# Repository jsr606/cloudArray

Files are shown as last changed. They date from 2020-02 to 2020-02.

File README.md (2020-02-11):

# cloud array
github repository for the tech side of the permanent installation "cloud array".

this installation lives permanently at [søndervangskolen](https://soendervangskolen.aarhus.dk/) in viby, århus, denmark. you can see the installation from the inside as well as the outside 24 hours a day, all year.

for more information visit this website www.jacobremin.com/cloudArray

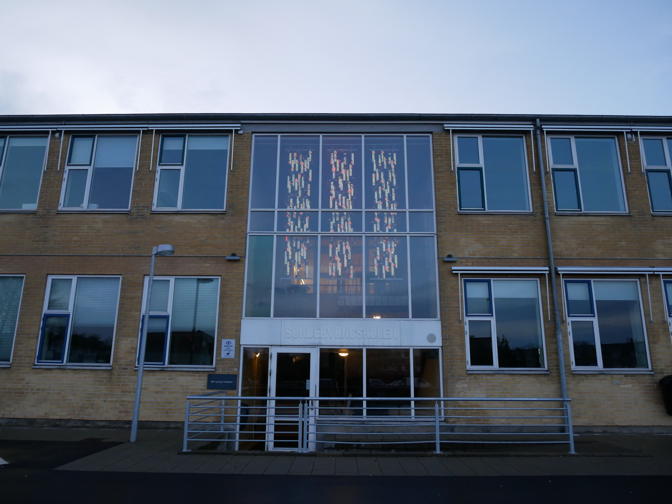
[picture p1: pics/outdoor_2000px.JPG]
installation view, photo by jacob remin

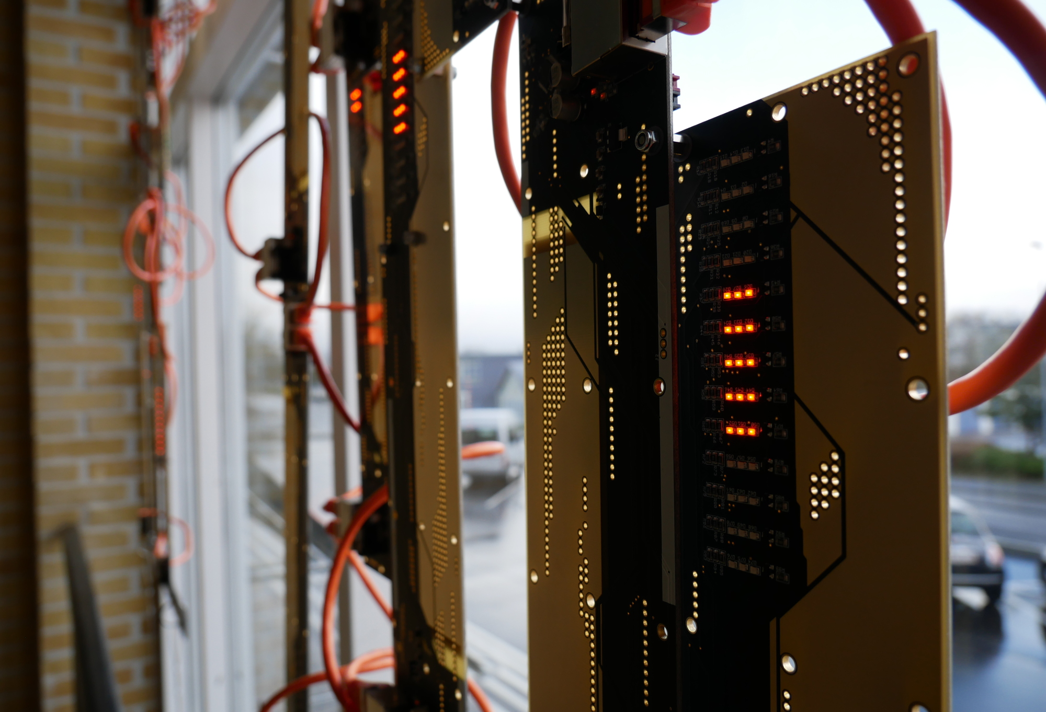
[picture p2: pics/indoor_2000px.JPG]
installation detail, photo by jacob remin


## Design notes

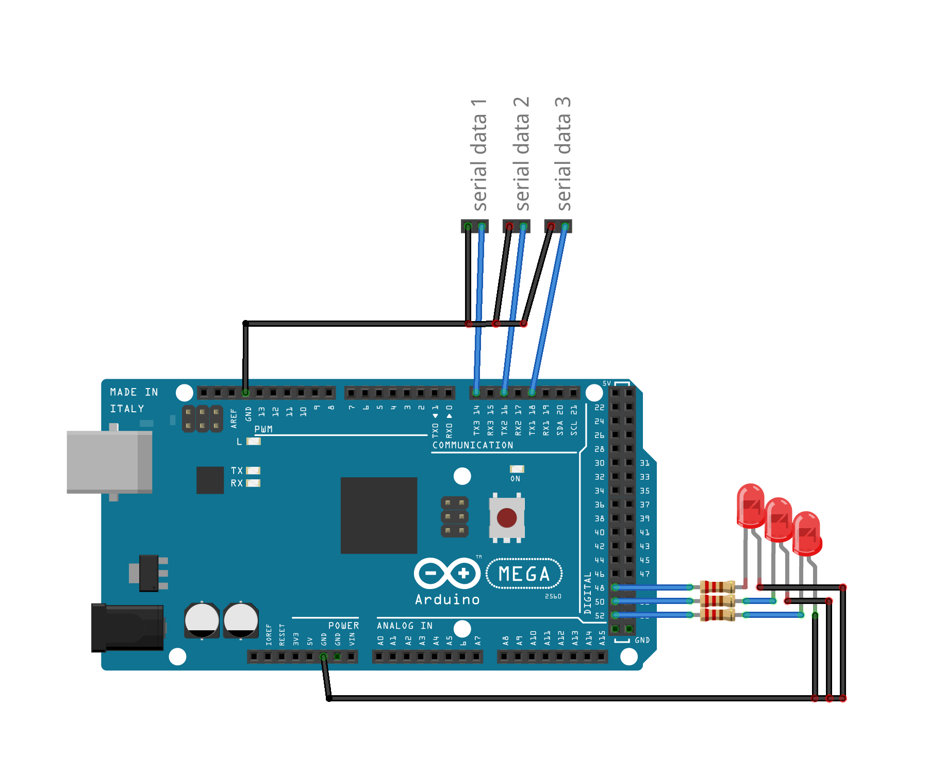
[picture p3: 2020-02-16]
hardware and documentation/mega conductor.png

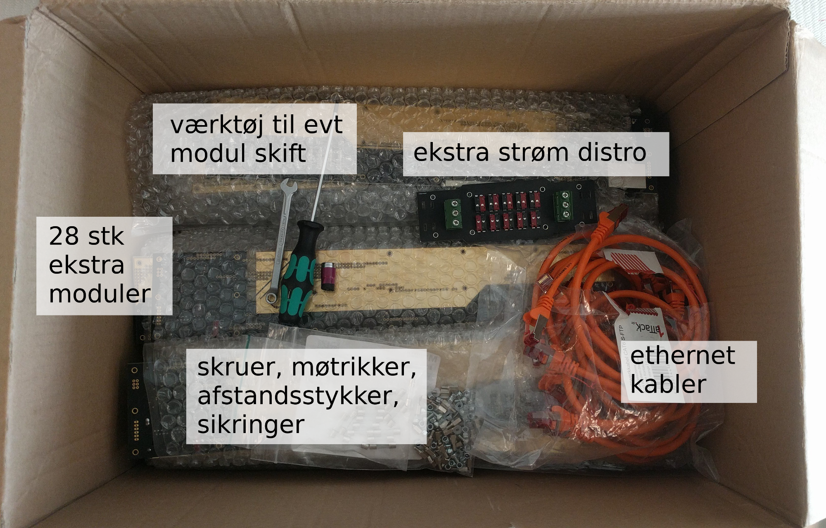
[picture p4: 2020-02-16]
hardware and documentation/extra things for søndervangskolen.png

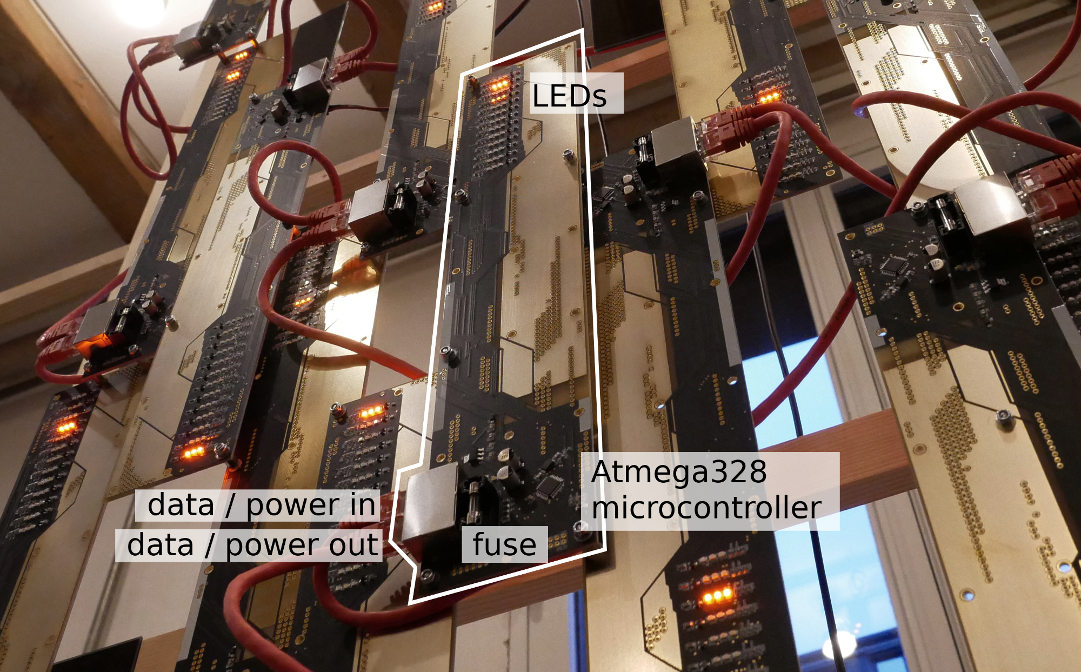
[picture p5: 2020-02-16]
hardware and documentation/annotated module.png

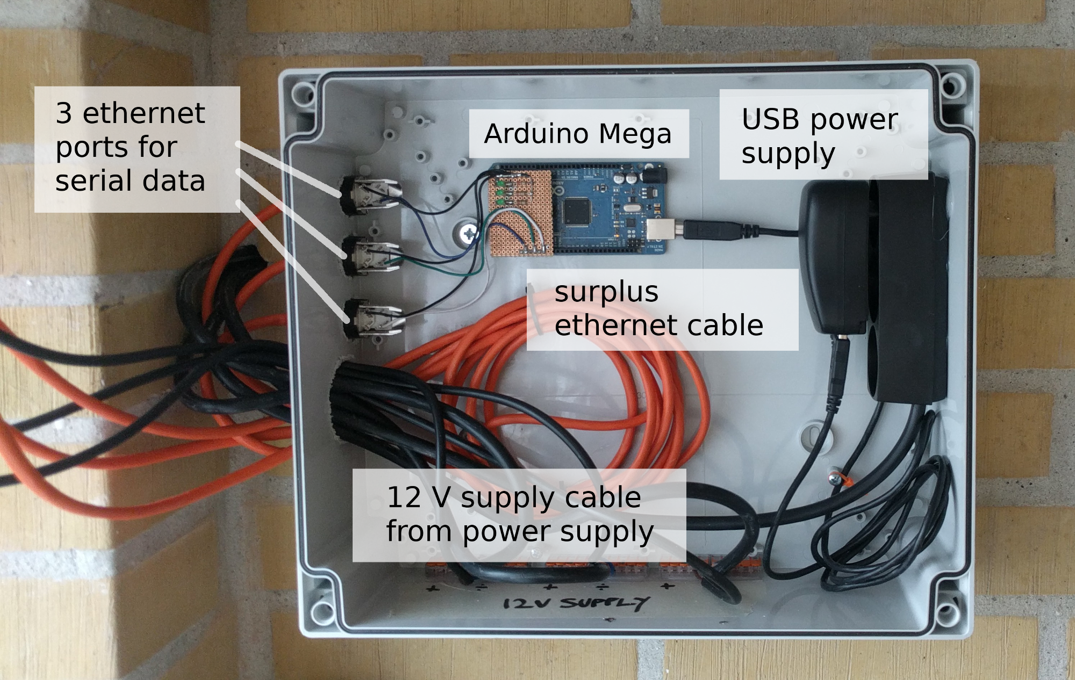
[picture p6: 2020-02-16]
hardware and documentation/annotated control box.png

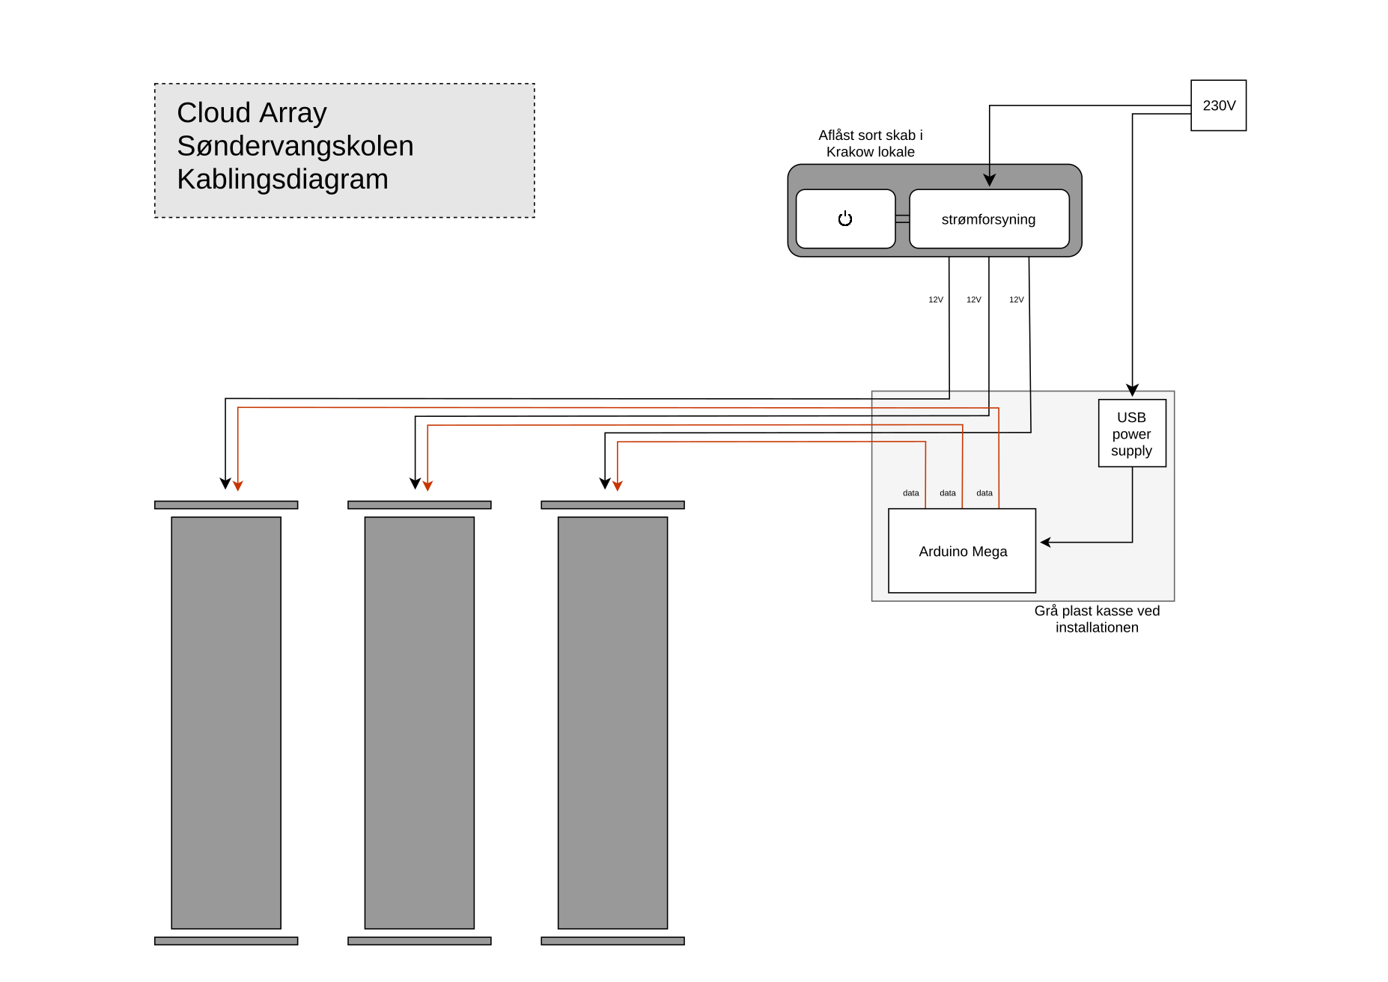
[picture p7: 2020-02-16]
hardware and documentation/cloud array kablingsdiagram.pdf.png

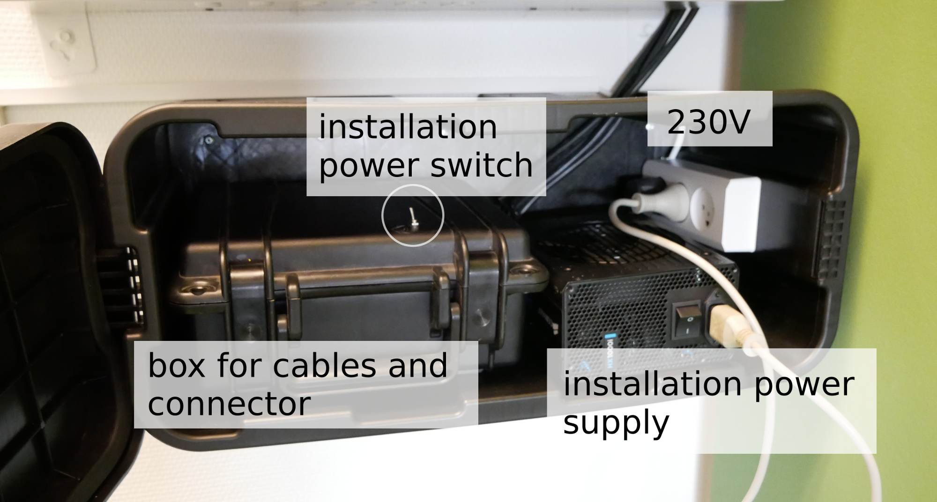
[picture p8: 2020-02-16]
hardware and documentation/annotated power cabinet.png

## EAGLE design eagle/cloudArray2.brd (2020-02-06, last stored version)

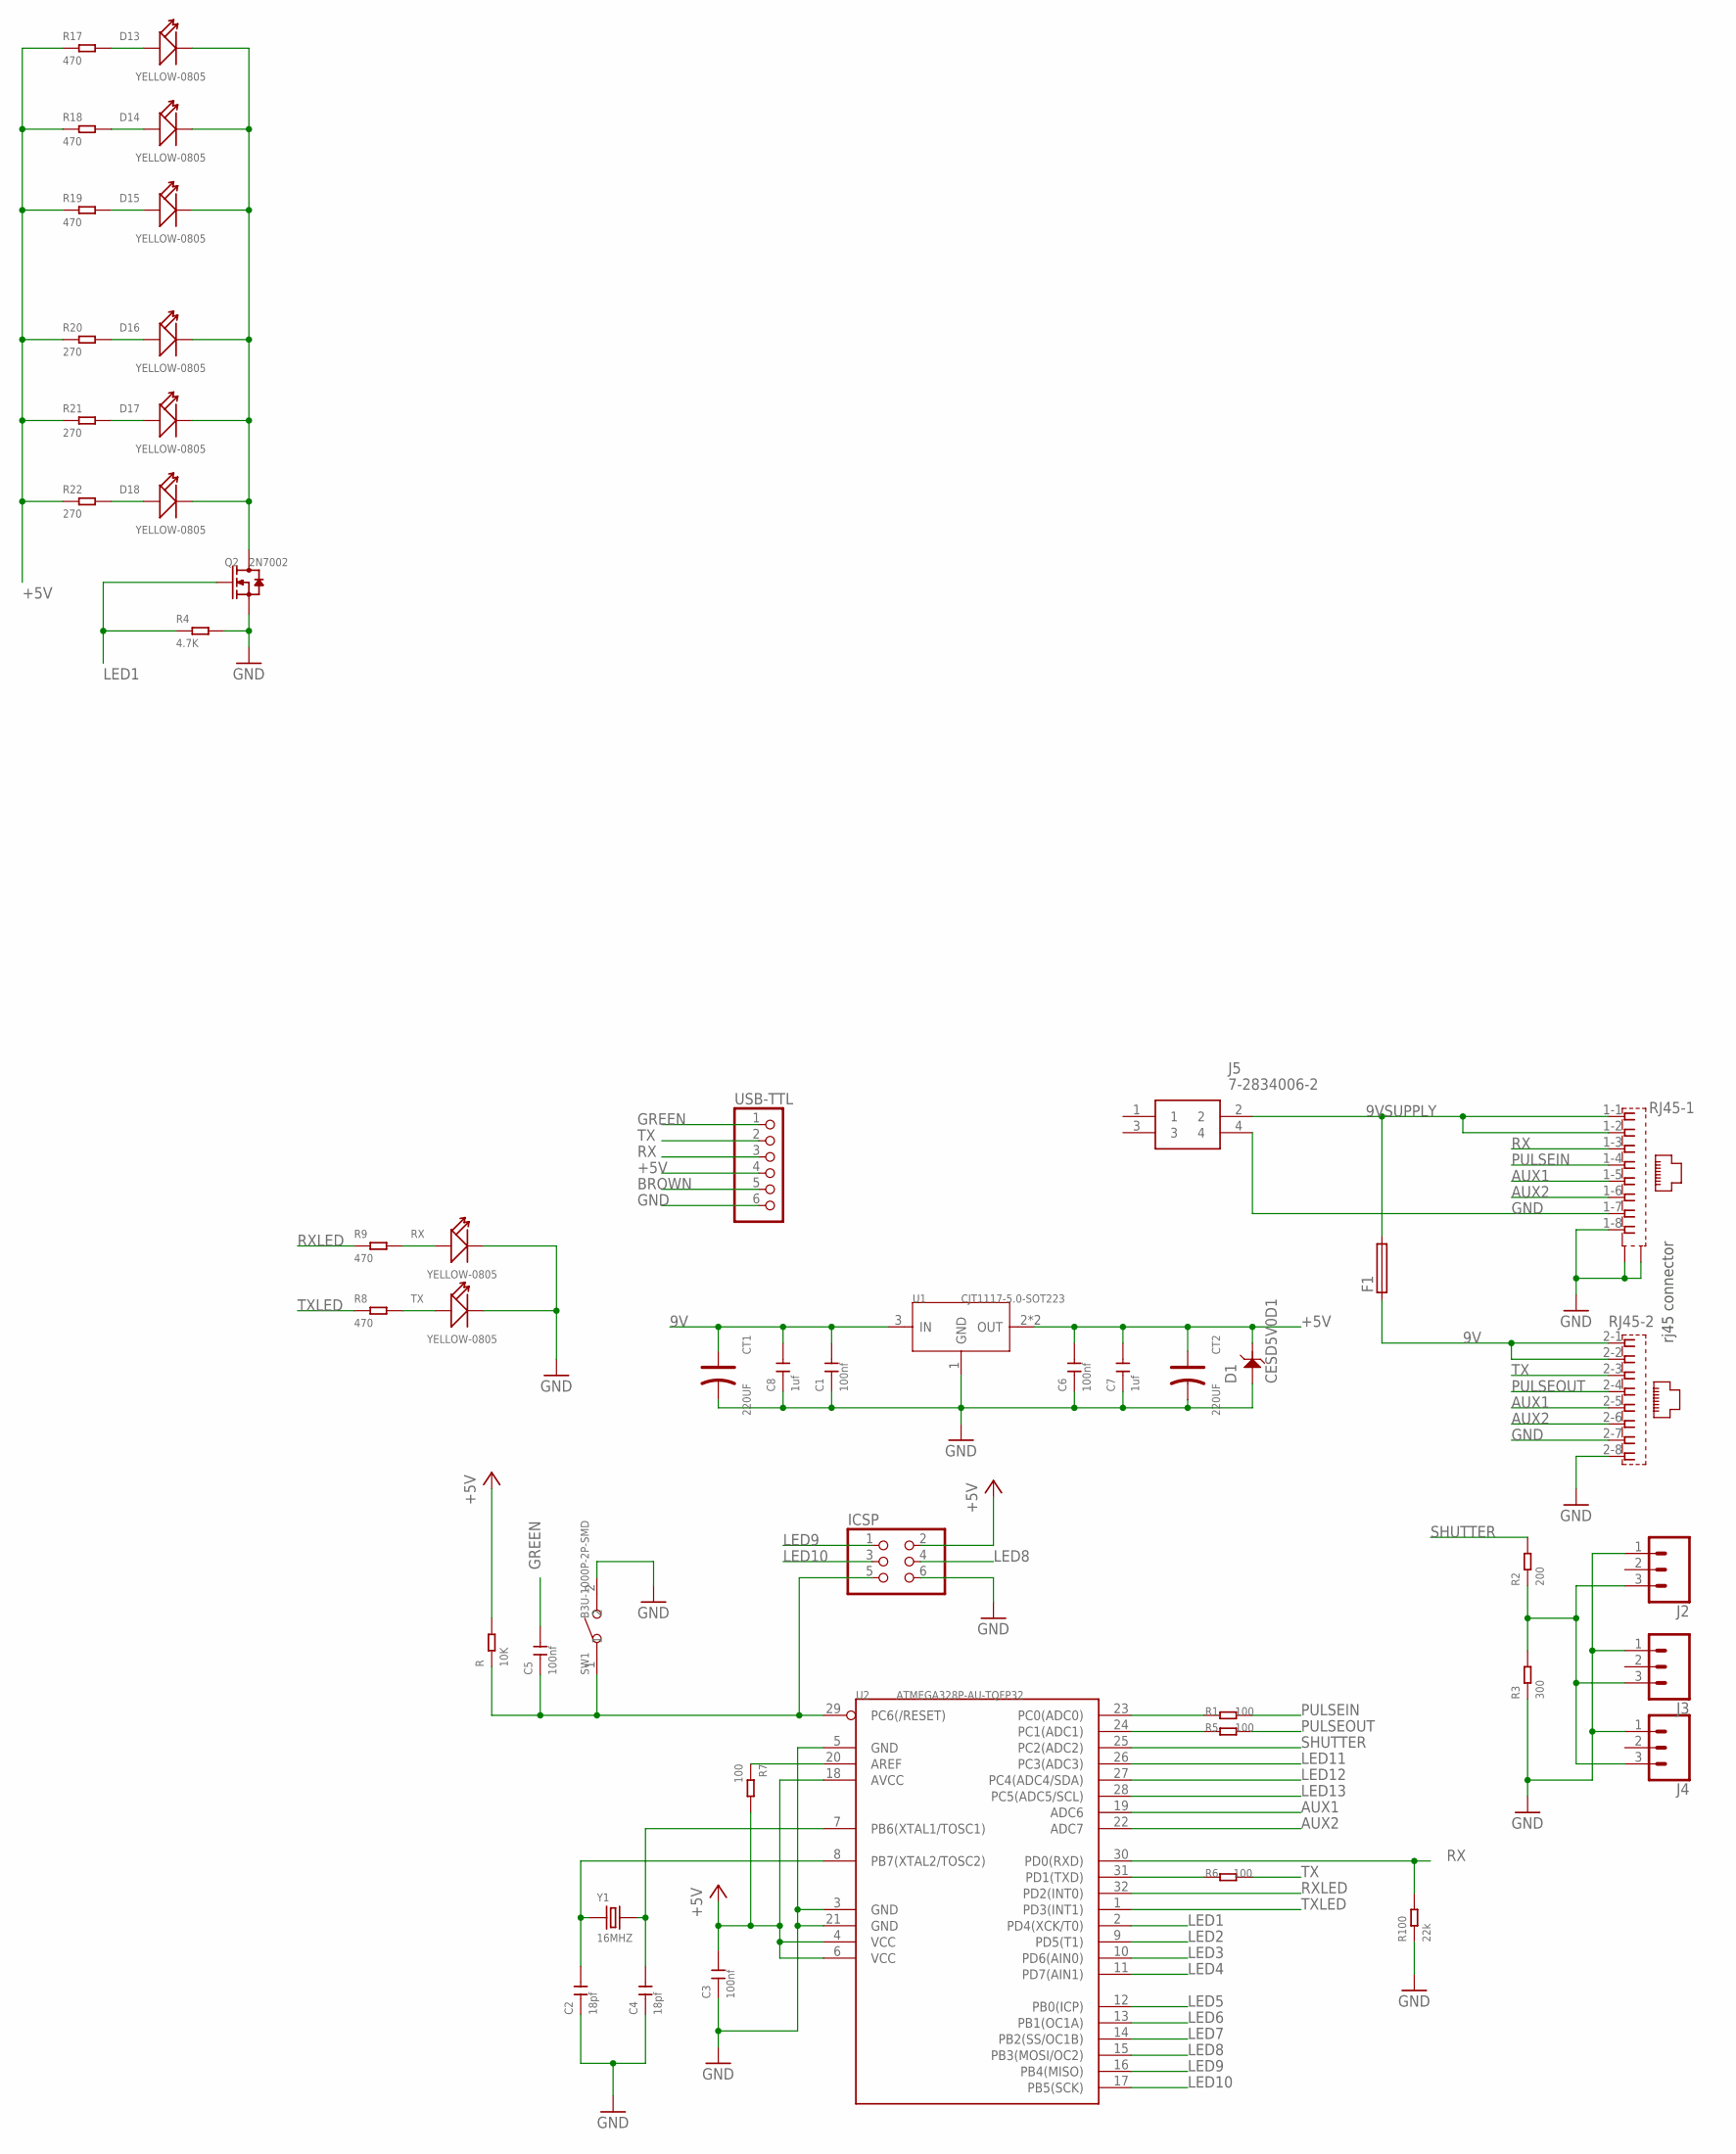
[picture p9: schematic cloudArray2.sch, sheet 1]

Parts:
C1, C3, C5, C6: 100nf; C0805
C2, C4: 18pf; C0805
C7, C8: 1uf; C0805
CT1, CT2: 220UF; ELECTRO-SMD-C-6MM
D1: CESD5V0D1; SOD-123
D13, D14, D15, D16, D17, D18: YELLOW-0805; LED-0805
F1: SH22,5A
ICSP: PINHD-2X3; 2X03
J2, J3, J4: 455-1750-1-ND; 1X03
J5: 7-2834006-2; 728340062
Q2: 2N7002; SOT-23
R: 10K; R0805
R1, R5, R6, R7: 100; R0805
R2: 200; R0805
R3: 300; R0805
R4: 4.7K; R0805
R8, R9, R17, R18, R19: 470; R0805
R20, R21, R22: 270; R0805
R100: 22k; R0805
RJ45: 557570-1
RX: YELLOW-0805; LED-0805
SW1: B3U-1000P-2P-SMD; SW2-2.6-3.0X2.5X1.2+0.4MM
TX: YELLOW-0805; LED-0805
U1: CJT1117-5.0-SOT223; SOT-223
U2: ATMEGA328P-AU-TQFP32; TQFP32-0.8-7X7MM
USB-TTL: PINHD-1X6; 1X06
Y1: 16MHZ; X2-SMD-5.0X3.2X1.3MM

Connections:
9V: C1.2, C8.2, CT1.+, F1.1, RJ45.2-1 (1), RJ45.2-2 (2), U1.3 (IN)
9VSUPPLY: F1.2, J5.2, RJ45.1-1 (1), RJ45.1-2 (2)
+5V: C3.2, C6.2, C7.2, CT2.+, D1.- (2), ICSP.2, R.2, R7.2, R17.1, R18.1, R19.1, R20.1, R21.1, R22.1, U1.2 (OUT), U1.TER (OUT), U2.4 (VCC), U2.6 (VCC), U2.18 (AVCC), USB-TTL.4; also elsewhere on the board
A0: R1.2, U2.23 (PC0(ADC0))
A1: R5.2, U2.24 (PC1(ADC1))
AREF: R7.1, U2.20 (AREF)
AUX1: RJ45.1-5 (5), RJ45.2-5 (5), U2.19 (ADC6)
AUX2: RJ45.1-6 (6), RJ45.2-6 (6), U2.22 (ADC7)
BROWN: USB-TTL.5
GND: C1.1, C2.1, C3.1, C4.1, C6.1, C7.1, C8.1, CT1.-, CT2.-, D1.+ (1), ICSP.6, J2.1, J3.1, J4.1, J5.4, Q2.2 (S), R3.1, R4.2, R100.1, RJ45.1-7 (7), RJ45.1-8 (8), RJ45.2-7 (7), RJ45.2-8 (8), RJ45.G1 (S2), RJ45.G3 (S1), RX.-, SW1.2, TX.-, U1.1 (GND), U2.3 (GND), U2.5 (GND), U2.21 (GND), USB-TTL.6; also elsewhere on the board
GREEN: C5.2, USB-TTL.1
LED1: Q2.1 (G), R4.1, U2.2 (PD4(XCK/T0))
LED2: U2.9 (PD5(T1)); also elsewhere on the board
LED3: U2.10 (PD6(AIN0)); also elsewhere on the board
LED4: U2.11 (PD7(AIN1)); also elsewhere on the board
LED5: U2.12 (PB0(ICP)); also elsewhere on the board
LED6: U2.13 (PB1(OC1A)); also elsewhere on the board
LED7: U2.14 (PB2(SS/OC1B)); also elsewhere on the board
LED8: ICSP.4, U2.15 (PB3(MOSI/OC2)); also elsewhere on the board
LED9: ICSP.1, U2.16 (PB4(MISO)); also elsewhere on the board
LED10: ICSP.3, U2.17 (PB5(SCK)); also elsewhere on the board
LED11: U2.26 (PC3(ADC3)); also elsewhere on the board
LED12: U2.27 (PC4(ADC4/SDA)); also elsewhere on the board
LED13: U2.28 (PC5(ADC5/SCL)); also elsewhere on the board
unnamed: D13.-, D14.-, D15.-, D16.-, D17.-, D18.-, Q2.3 (D)
unnamed: C2.2, U2.8 (PB7(XTAL2/TOSC2)), Y1.1
unnamed: C4.2, U2.7 (PB6(XTAL1/TOSC1)), Y1.2
unnamed: R6.2, U2.31 (PD1(TXD))
unnamed: R8.2, TX.+
unnamed: J2.3, J3.3, J4.3, R2.1, R3.2
unnamed: R9.2, RX.+
unnamed: D13.+, R17.2
unnamed: D14.+, R18.2
unnamed: D15.+, R19.2
unnamed: D16.+, R20.2
unnamed: D17.+, R21.2
unnamed: D18.+, R22.2
PULSEIN: R1.1, RJ45.1-4 (4)
PULSEOUT: R5.1, RJ45.2-4 (4)
RESET: C5.1, ICSP.5, R.1, SW1.1, U2.29 (PC6(/RESET))
RX: R100.2, RJ45.1-3 (3), U2.30 (PD0(RXD)), USB-TTL.3
RXLED: R9.1, U2.32 (PD2(INT0))
SHUTTER: R2.2, U2.25 (PC2(ADC2))
TX: R6.1, RJ45.2-3 (3), USB-TTL.2
TXLED: R8.1, U2.1 (PD3(INT1))

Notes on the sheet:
rj45 connector

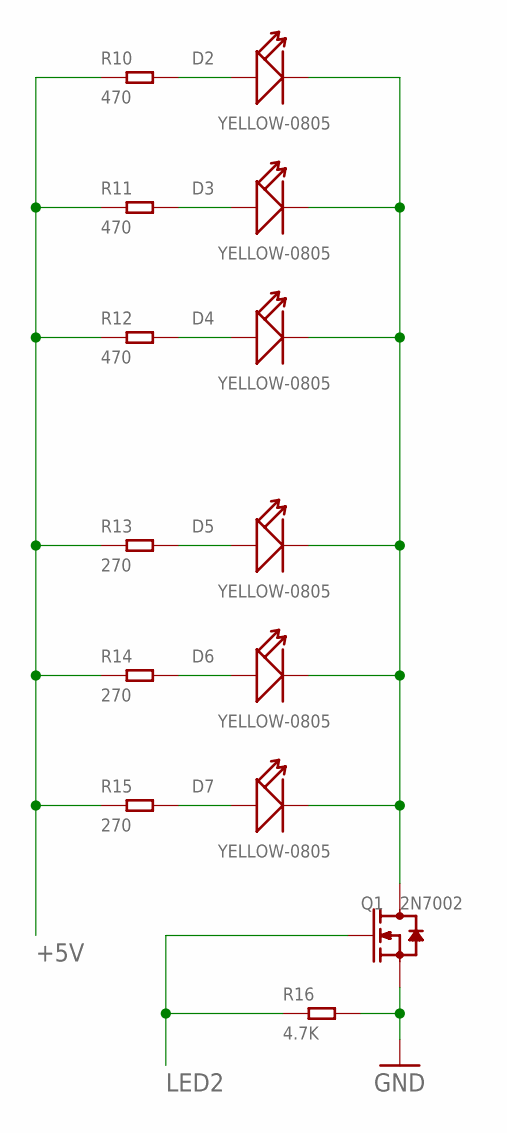
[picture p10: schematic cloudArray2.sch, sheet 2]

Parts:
D2, D3, D4, D5, D6, D7: YELLOW-0805; LED-0805
Q1: 2N7002; SOT-23
R10, R11, R12: 470; R0805
R13, R14, R15: 270; R0805
R16: 4.7K; R0805

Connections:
+5V: R10.1, R11.1, R12.1, R13.1, R14.1, R15.1; also elsewhere on the board
GND: Q1.2 (S), R16.2; also elsewhere on the board
LED2: Q1.1 (G), R16.1; also elsewhere on the board
unnamed: D2.+, R10.2
unnamed: D3.+, R11.2
unnamed: D4.+, R12.2
unnamed: D5.+, R13.2
unnamed: D6.+, R14.2
unnamed: D7.+, R15.2
unnamed: D2.-, D3.-, D4.-, D5.-, D6.-, D7.-, Q1.3 (D)

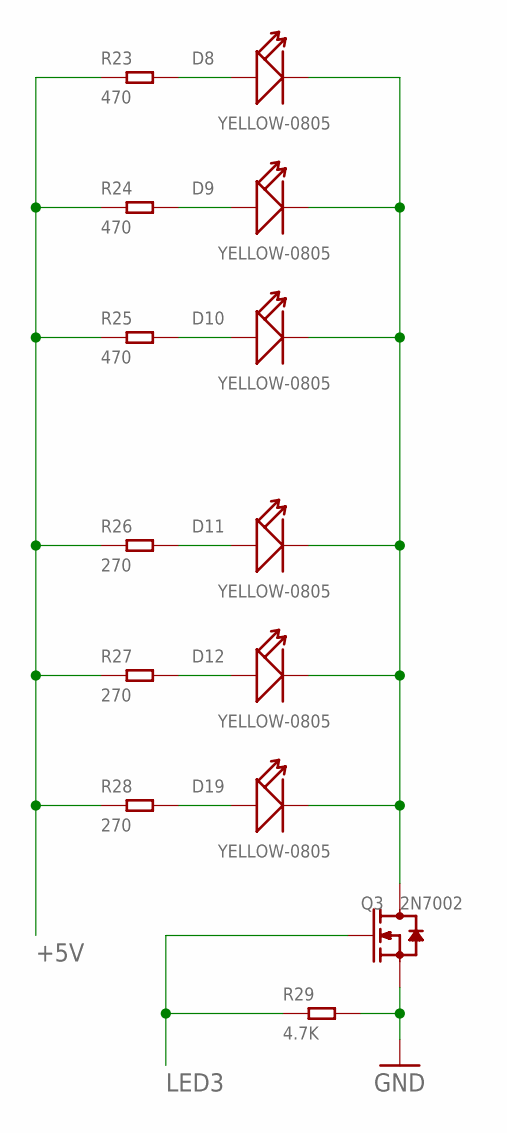
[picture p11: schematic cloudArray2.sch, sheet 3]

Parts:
D8, D9, D10, D11, D12, D19: YELLOW-0805; LED-0805
Q3: 2N7002; SOT-23
R23, R24, R25: 470; R0805
R26, R27, R28: 270; R0805
R29: 4.7K; R0805

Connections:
+5V: R23.1, R24.1, R25.1, R26.1, R27.1, R28.1; also elsewhere on the board
GND: Q3.2 (S), R29.2; also elsewhere on the board
LED3: Q3.1 (G), R29.1; also elsewhere on the board
unnamed: D8.+, R23.2
unnamed: D9.+, R24.2
unnamed: D10.+, R25.2
unnamed: D11.+, R26.2
unnamed: D12.+, R27.2
unnamed: D19.+, R28.2
unnamed: D8.-, D9.-, D10.-, D11.-, D12.-, D19.-, Q3.3 (D)

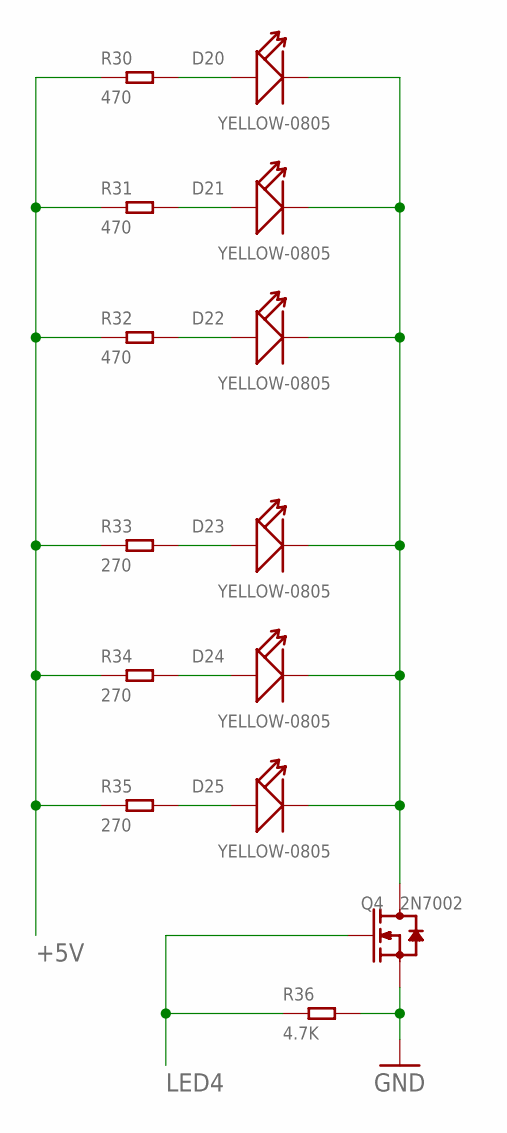
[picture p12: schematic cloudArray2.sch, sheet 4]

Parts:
D20, D21, D22, D23, D24, D25: YELLOW-0805; LED-0805
Q4: 2N7002; SOT-23
R30, R31, R32: 470; R0805
R33, R34, R35: 270; R0805
R36: 4.7K; R0805

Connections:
+5V: R30.1, R31.1, R32.1, R33.1, R34.1, R35.1; also elsewhere on the board
GND: Q4.2 (S), R36.2; also elsewhere on the board
LED4: Q4.1 (G), R36.1; also elsewhere on the board
unnamed: D20.+, R30.2
unnamed: D21.+, R31.2
unnamed: D22.+, R32.2
unnamed: D23.+, R33.2
unnamed: D24.+, R34.2
unnamed: D25.+, R35.2
unnamed: D20.-, D21.-, D22.-, D23.-, D24.-, D25.-, Q4.3 (D)

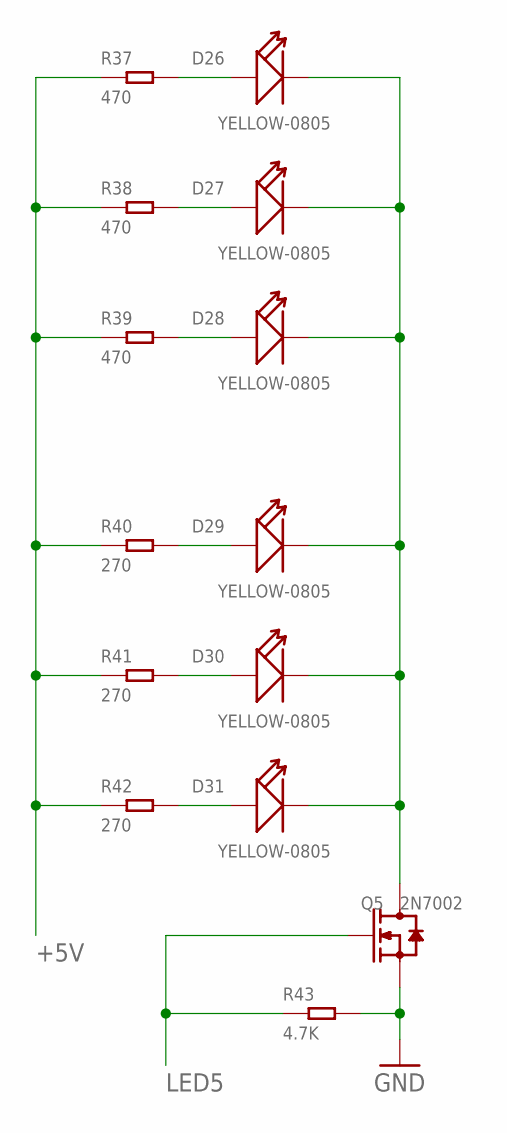
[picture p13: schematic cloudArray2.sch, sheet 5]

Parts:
D26, D27, D28, D29, D30, D31: YELLOW-0805; LED-0805
Q5: 2N7002; SOT-23
R37, R38, R39: 470; R0805
R40, R41, R42: 270; R0805
R43: 4.7K; R0805

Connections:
+5V: R37.1, R38.1, R39.1, R40.1, R41.1, R42.1; also elsewhere on the board
GND: Q5.2 (S), R43.2; also elsewhere on the board
LED5: Q5.1 (G), R43.1; also elsewhere on the board
unnamed: D26.+, R37.2
unnamed: D27.+, R38.2
unnamed: D28.+, R39.2
unnamed: D29.+, R40.2
unnamed: D30.+, R41.2
unnamed: D31.+, R42.2
unnamed: D26.-, D27.-, D28.-, D29.-, D30.-, D31.-, Q5.3 (D)

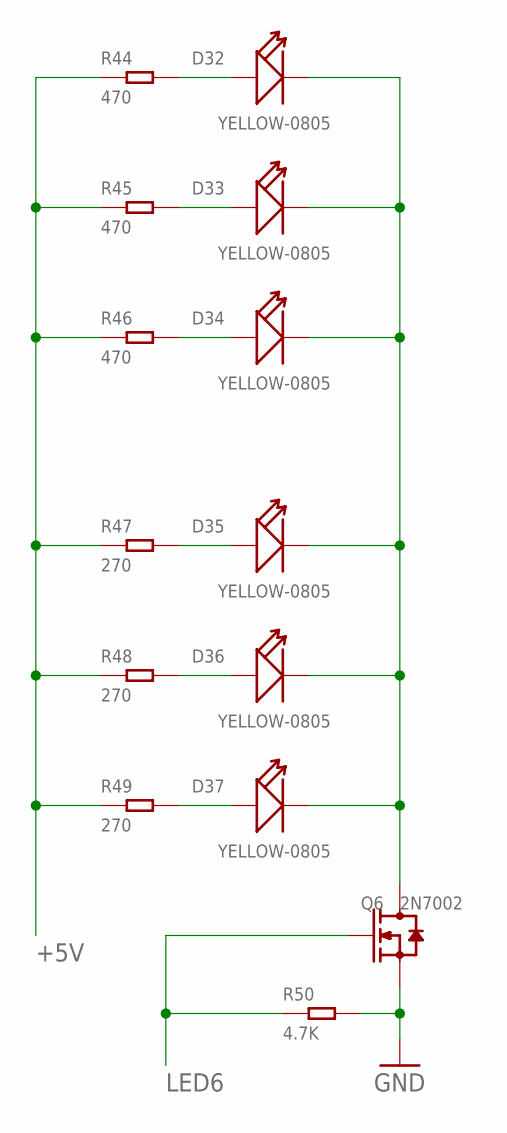
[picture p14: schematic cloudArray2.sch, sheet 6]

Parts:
D32, D33, D34, D35, D36, D37: YELLOW-0805; LED-0805
Q6: 2N7002; SOT-23
R44, R45, R46: 470; R0805
R47, R48, R49: 270; R0805
R50: 4.7K; R0805

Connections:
+5V: R44.1, R45.1, R46.1, R47.1, R48.1, R49.1; also elsewhere on the board
GND: Q6.2 (S), R50.2; also elsewhere on the board
LED6: Q6.1 (G), R50.1; also elsewhere on the board
unnamed: D32.+, R44.2
unnamed: D33.+, R45.2
unnamed: D34.+, R46.2
unnamed: D35.+, R47.2
unnamed: D36.+, R48.2
unnamed: D37.+, R49.2
unnamed: D32.-, D33.-, D34.-, D35.-, D36.-, D37.-, Q6.3 (D)

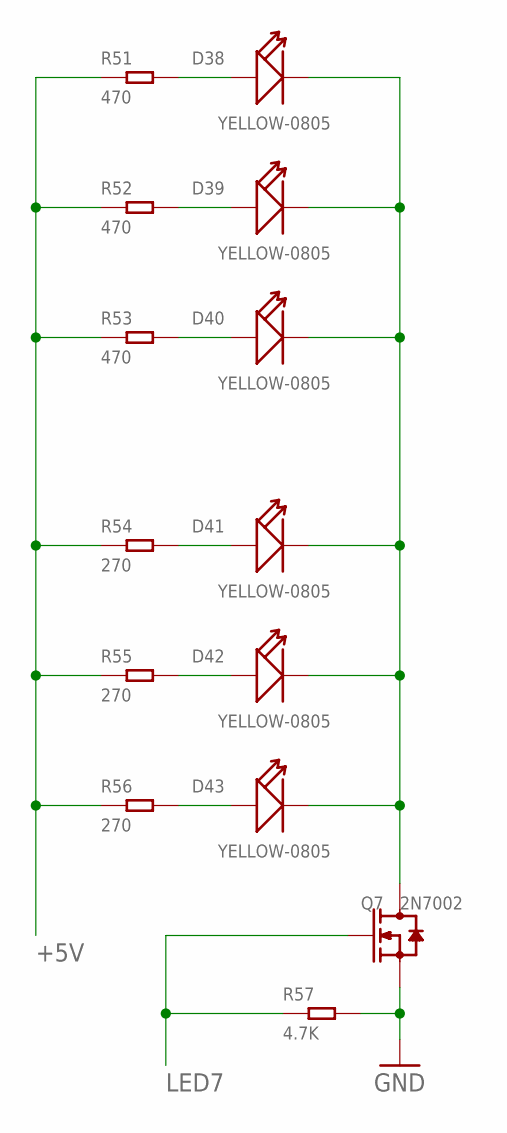
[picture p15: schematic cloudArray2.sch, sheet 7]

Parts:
D38, D39, D40, D41, D42, D43: YELLOW-0805; LED-0805
Q7: 2N7002; SOT-23
R51, R52, R53: 470; R0805
R54, R55, R56: 270; R0805
R57: 4.7K; R0805

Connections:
+5V: R51.1, R52.1, R53.1, R54.1, R55.1, R56.1; also elsewhere on the board
GND: Q7.2 (S), R57.2; also elsewhere on the board
LED7: Q7.1 (G), R57.1; also elsewhere on the board
unnamed: D38.+, R51.2
unnamed: D39.+, R52.2
unnamed: D40.+, R53.2
unnamed: D41.+, R54.2
unnamed: D42.+, R55.2
unnamed: D43.+, R56.2
unnamed: D38.-, D39.-, D40.-, D41.-, D42.-, D43.-, Q7.3 (D)

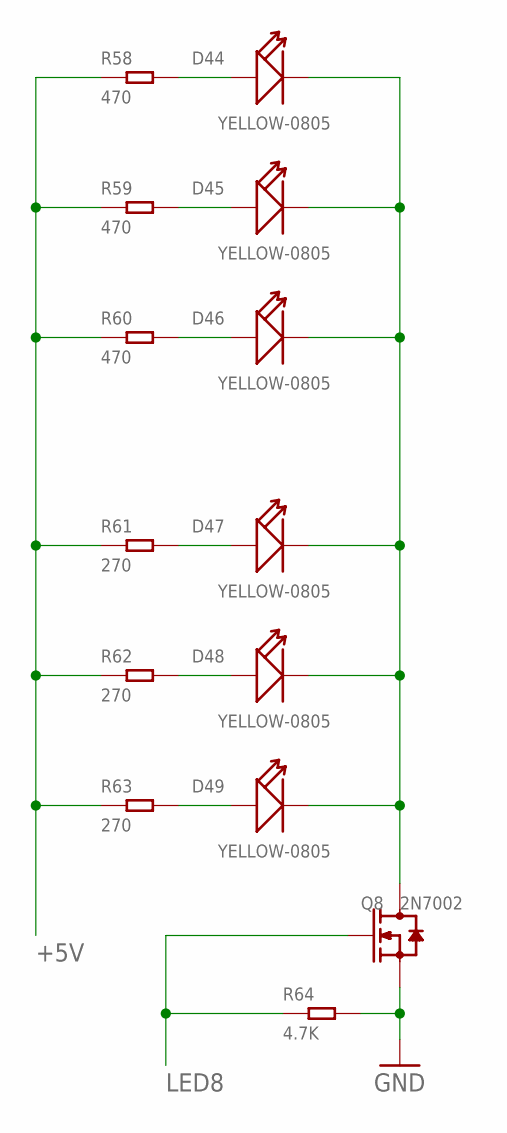
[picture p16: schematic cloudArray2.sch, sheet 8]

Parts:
D44, D45, D46, D47, D48, D49: YELLOW-0805; LED-0805
Q8: 2N7002; SOT-23
R58, R59, R60: 470; R0805
R61, R62, R63: 270; R0805
R64: 4.7K; R0805

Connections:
+5V: R58.1, R59.1, R60.1, R61.1, R62.1, R63.1; also elsewhere on the board
GND: Q8.2 (S), R64.2; also elsewhere on the board
LED8: Q8.1 (G), R64.1; also elsewhere on the board
unnamed: D44.+, R58.2
unnamed: D45.+, R59.2
unnamed: D46.+, R60.2
unnamed: D47.+, R61.2
unnamed: D48.+, R62.2
unnamed: D49.+, R63.2
unnamed: D44.-, D45.-, D46.-, D47.-, D48.-, D49.-, Q8.3 (D)

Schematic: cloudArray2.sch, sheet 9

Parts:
D50, D51, D52, D53, D54, D55: YELLOW-0805; LED-0805
Q9: 2N7002; SOT-23
R65, R66, R67: 470; R0805
R68, R69, R70: 270; R0805
R71: 4.7K; R0805

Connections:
+5V: R65.1, R66.1, R67.1, R68.1, R69.1, R70.1; also elsewhere on the board
GND: Q9.2 (S), R71.2; also elsewhere on the board
LED9: Q9.1 (G), R71.1; also elsewhere on the board
unnamed: D50.+, R65.2
unnamed: D51.+, R66.2
unnamed: D52.+, R67.2
unnamed: D53.+, R68.2
unnamed: D54.+, R69.2
unnamed: D55.+, R70.2
unnamed: D50.-, D51.-, D52.-, D53.-, D54.-, D55.-, Q9.3 (D)

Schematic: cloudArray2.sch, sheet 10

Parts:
D56, D57, D58, D59, D60, D61: YELLOW-0805; LED-0805
Q10: 2N7002; SOT-23
R72, R73, R74: 470; R0805
R75, R76, R77: 270; R0805
R78: 4.7K; R0805

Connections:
+5V: R72.1, R73.1, R74.1, R75.1, R76.1, R77.1; also elsewhere on the board
GND: Q10.2 (S), R78.2; also elsewhere on the board
LED10: Q10.1 (G), R78.1; also elsewhere on the board
unnamed: D56.+, R72.2
unnamed: D57.+, R73.2
unnamed: D58.+, R74.2
unnamed: D59.+, R75.2
unnamed: D60.+, R76.2
unnamed: D61.+, R77.2
unnamed: D56.-, D57.-, D58.-, D59.-, D60.-, D61.-, Q10.3 (D)

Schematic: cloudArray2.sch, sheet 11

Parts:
D62, D63, D64, D65, D66, D67: YELLOW-0805; LED-0805
Q11: 2N7002; SOT-23
R79, R80, R81: 470; R0805
R82, R83, R84: 270; R0805
R85: 4.7K; R0805

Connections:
+5V: R79.1, R80.1, R81.1, R82.1, R83.1, R84.1; also elsewhere on the board
GND: Q11.2 (S), R85.2; also elsewhere on the board
LED11: Q11.1 (G), R85.1; also elsewhere on the board
unnamed: D62.+, R79.2
unnamed: D63.+, R80.2
unnamed: D64.+, R81.2
unnamed: D65.+, R82.2
unnamed: D66.+, R83.2
unnamed: D67.+, R84.2
unnamed: D62.-, D63.-, D64.-, D65.-, D66.-, D67.-, Q11.3 (D)

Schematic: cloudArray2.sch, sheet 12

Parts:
D68, D69, D70, D71, D72, D73: YELLOW-0805; LED-0805
Q12: 2N7002; SOT-23
R86, R87, R88: 470; R0805
R89, R90, R91: 270; R0805
R92: 4.7K; R0805

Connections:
+5V: R86.1, R87.1, R88.1, R89.1, R90.1, R91.1; also elsewhere on the board
GND: Q12.2 (S), R92.2; also elsewhere on the board
LED12: Q12.1 (G), R92.1; also elsewhere on the board
unnamed: D68.+, R86.2
unnamed: D69.+, R87.2
unnamed: D70.+, R88.2
unnamed: D71.+, R89.2
unnamed: D72.+, R90.2
unnamed: D73.+, R91.2
unnamed: D68.-, D69.-, D70.-, D71.-, D72.-, D73.-, Q12.3 (D)

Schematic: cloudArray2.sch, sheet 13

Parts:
D74, D75, D76, D77, D78, D79: YELLOW-0805; LED-0805
Q13: 2N7002; SOT-23
R93, R94, R95: 470; R0805
R96, R97, R98: 270; R0805
R99: 4.7K; R0805

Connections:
+5V: R93.1, R94.1, R95.1, R96.1, R97.1, R98.1; also elsewhere on the board
GND: Q13.2 (S), R99.2; also elsewhere on the board
LED13: Q13.1 (G), R99.1; also elsewhere on the board
unnamed: D74.+, R93.2
unnamed: D75.+, R94.2
unnamed: D76.+, R95.2
unnamed: D77.+, R96.2
unnamed: D78.+, R97.2
unnamed: D79.+, R98.2
unnamed: D74.-, D75.-, D76.-, D77.-, D78.-, D79.-, Q13.3 (D)

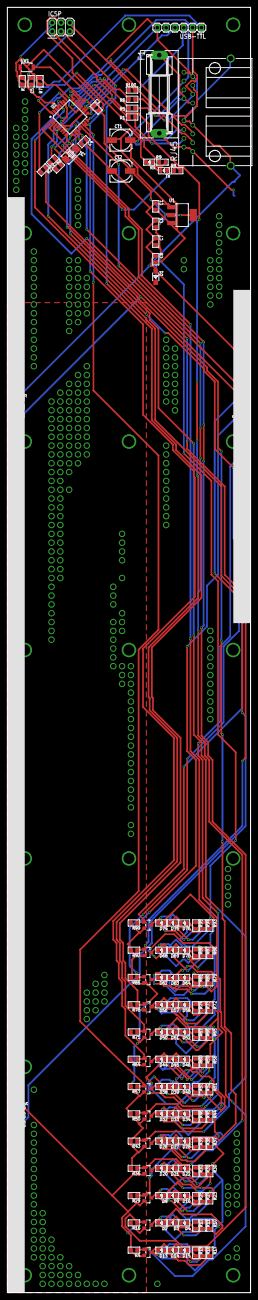
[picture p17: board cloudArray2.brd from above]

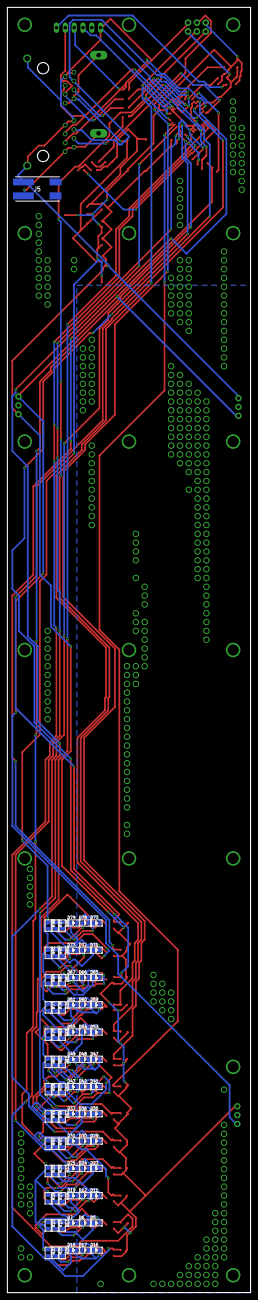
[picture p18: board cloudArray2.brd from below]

Board: 2 copper layers, 70.0 x 370.0 mm, 217 parts (79 on the bottom side), 128 nets.

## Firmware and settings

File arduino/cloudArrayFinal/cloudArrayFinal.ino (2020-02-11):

#include <SoftPWM.h>

int led [] = {4, 5, 6, 7, 8, 9, 10, 11, 12, 13, A3, A4, A5};
int amountOfLeds = 13;
int maxPWM = 35;

int pulseInput = A0, pulseOutput = A1;
int lcdShutter = A2;
int rxLed = 2, txLed = 3;

int delayMultiplier = 1;
int transmitDelay = 0;
int stepDelay = 150;
unsigned long nextStep = millis() + stepDelay;

int intensity = 20, fadeIn = 0, fadeOut = 4000, probability = 40;

int lcdDelay = 3000;
boolean lcdShut = false, lcdActive = true;

int burstDuration = 0;
unsigned long burstEnd = millis() + burstDuration;
boolean bursting = false, autoBursting = true;
int autoBurstFrequency = 10000;
int oldProbability = probability;
boolean directionalRunning = false;

unsigned long nextShutter = millis() + lcdDelay;
int id = 10;

int program = 2;
#define REST 0
#define STARS 1
#define KNIGHTRIDER 2
#define SOLID 3
#define BLINKSOLID 4
#define VU 5
#define MIDDLEVU 6
#define DIRECTIONAL 7
#define RANDOMBITS 8

boolean feedback = false;

// program specific globals
int vuValue = 0;
int knightRiderLed = 0, knightRiderDirection = 1;
int blinkStep = 0;

void setup() {
  SoftPWMBegin();
  for (int i = 0; i < amountOfLeds; i++) {
    pinMode(led[i], OUTPUT);
    SoftPWMSet(led[i], 0);
  }
  SoftPWMSetFadeTime(ALL, fadeIn, fadeOut);

  pinMode(lcdShutter, OUTPUT);
  pinMode(pulseOutput, OUTPUT);
  pinMode(rxLed, OUTPUT);
  pinMode(txLed, OUTPUT);

  Serial.begin(115200);

  digitalWrite(rxLed, HIGH);
  digitalWrite(txLed, HIGH);

  for (int i = 0; i < amountOfLeds; i++) {
    digitalWrite(led[i], HIGH);
    delay(50);
    digitalWrite(led[i], LOW);
  }

  digitalWrite(rxLed, LOW);
  digitalWrite(txLed, LOW);

  Serial.flush();
}

void loop() {

  if (Serial.available() > 2) {

    digitalWrite(rxLed, HIGH);

    byte startByte = Serial.read();
    if (startByte == 255) {
      
      // startbyte 255, one value
      byte command, value;
      command = Serial.read();
      value = Serial.read();
      parseIncomingSerial(command, value);
      
      delay(transmitDelay * delayMultiplier);
      sendData(command, value);
      
    } else if (startByte == 254) {
      
      // startbyte 254, two values
      byte command, value1, value2;
      command = Serial.read();
      value1 = Serial.read();
      value2 = Serial.read();
      parseIncomingSerial(command, value1, value2);
      
    } else {
      // doesn't make sense, just pass it along anyways
      digitalWrite(txLed, HIGH);
      Serial.write(startByte);
      digitalWrite(txLed, LOW);
    }

    digitalWrite(rxLed, LOW);
  }

  if (millis() > nextStep) {

    switch (program) {
      case REST:
        // do nothing
        break;
      case KNIGHTRIDER:
        knightRider();
        break;
      case STARS:
        stars();
        break;
      case SOLID:
        solid();
        break;
      case BLINKSOLID:
        blinkSolid();
        break;
      case VU:
        vu();
        break;
      case MIDDLEVU:
        middleVu();
        break;
      case DIRECTIONAL:
        directional();
        break;
      case RANDOMBITS:
        randomBits();
        break;
    }

    nextStep = millis() + stepDelay;

  }

  if (bursting && millis() > burstEnd) {
    bursting = false;
    probability = oldProbability;
  }

  if (autoBursting && millis() > burstEnd + autoBurstFrequency) {
    createBurst();
  }

  if (lcdActive && millis() > nextShutter) {
    lcdShut = !lcdShut;
    digitalWrite(lcdShutter, lcdShut);
    nextShutter = millis() + lcdDelay;
  }

}

void solid() {
  int pwmVal = map(intensity, 0, 100, 0, maxPWM);
  pwmVal = constrain(pwmVal, 0, maxPWM);
  for (int i = 0; i < amountOfLeds; i++) {
    SoftPWMSet(led[i], pwmVal);
  }
}

void blinkSolid() {
  blinkStep++;
  blinkStep = blinkStep % 100;
  if (blinkStep % intensity == 0) {
    for (int i = 0; i < amountOfLeds; i++) {
      SoftPWMSet(led[i], maxPWM);
    }
  }
  else {
    for (int i = 0; i < amountOfLeds; i++) {
      SoftPWMSet(led[i], 0);
    }
  }

}
void randomBits() {
  int chance = map(probability, 0, 100, 100, 0);
  int r = random(chance);
  if (r == 0) {
    for (int i = 0; i < amountOfLeds; i++) {
      int on = random(100);
      if (on < intensity) {
        SoftPWMSet(led[i], maxPWM);
      } else {

        SoftPWMSet(led[i], 0);
      }
    }
  }
}

void stars() {
  int chance = map(probability, 0, 100, 100, 0);
  int r = random(chance);
  if (r == 0) {
    int l = random(amountOfLeds);
    SoftPWMSet(led[l], maxPWM);
    delay(5);
    SoftPWMSet(led[l], 0);
  }
}

void middleVu() {
  int chance = map(probability, 0, 100, 100, 0);
  int r = random(chance);
  if (r == 0) {
    int v = random(7);
    for (int i = 0; i < 7; i++) {
      if (i < v) {
        SoftPWMSet(led[6 - i], maxPWM);
        SoftPWMSet(led[6 + i], maxPWM);
      } else {
        SoftPWMSet(led[6 - i], 0);
        SoftPWMSet(led[6 + i], 0);
      }
    }
  }
}

void vu() {
  int chance = map(probability, 0, 100, 100, 0);
  int r = random(chance);
  if (r == 0) {
    int v = random(14);
    for (int i = 0; i < amountOfLeds; i++) {
      if (i < v) {
        SoftPWMSet(led[i], maxPWM);
      } else {
        SoftPWMSet(led[i], 0);
      }
    }
  }
}

void directional() {
  if (!directionalRunning) {

    int chance = map(probability, 0, 100, 100, 0);
    int r = random(chance);
    if (r == 0) {
      int dir = random(2);
      if (dir == 0) {
        knightRiderDirection = -1;
        knightRiderLed = amountOfLeds;
      } else {
        knightRiderDirection = 1;
        knightRiderLed = 0;
      }
      directionalRunning = true;
    }

  }
  if (directionalRunning) {

    for (int i = 0; i < amountOfLeds; i++) {
      if (i == knightRiderLed) {
        SoftPWMSet(led[i], maxPWM);
      } else {
        SoftPWMSet(led[i], 0);
      }
    }

    knightRiderLed += knightRiderDirection;

    if (knightRiderLed < -1 || knightRiderLed > amountOfLeds + 1) {
      directionalRunning = false;
      for (int i = 0; i < amountOfLeds; i++) {
        SoftPWMSet(led[i], 0);
      }
    }
  }
}

void knightRider() {
  if (knightRiderDirection == 1) {
    knightRiderLed ++;
    if (knightRiderLed > amountOfLeds) {
      knightRiderDirection = -1;
      knightRiderLed = amountOfLeds - 1;
    }
  }
  if (knightRiderDirection == -1) {
    knightRiderLed --;
    if (knightRiderLed < 0) {
      knightRiderDirection = 1;
      knightRiderLed = 1;
    }
  }
  for (int i = 0; i < amountOfLeds; i++) {
    if (i == knightRiderLed) {
      SoftPWMSet(led[i], maxPWM);
    } else {
      SoftPWMSet(led[i], 0);
    }
  }
}

void parseIncomingSerial(char command, byte value1, byte value2) {
  if (command == 's') {
    digitalWrite(txLed, HIGH);
    stepDelay = value1;
    Serial.print("step delay is ");
    Serial.println(stepDelay);
    int offset = value2;
    offset = offset - 100;
    Serial.print("offset is ");
    Serial.println(offset);
    int newStepDelay = stepDelay + offset;
    byte newValue1 = constrain(newStepDelay, 0, 250);
    Serial.println(newStepDelay);
    sendDoubleData('s', newValue1, value2);
    delay(5);
    digitalWrite(txLed, LOW);
  }
}

void parseIncomingSerial(char command, byte value) {
  if (command == 'T') {
    transmitDelay = value;
    if (feedback) Serial.print("transmitDelay set to ");
    if (feedback) Serial.println(int(value));
  }
  if (command == 'M') {
    delayMultiplier = value;
    if (feedback) Serial.print("delayMultiplier set to ");
    if (feedback) Serial.println(byte(value));
  }
  if (command == 'P') {
    program = value;
    if (feedback) Serial.println(byte(value));
  }
  if (command == 'S') {
    stepDelay = value;
  }
  if (command == 's') {
    stepDelay = map(id, 0, 100, value/10, value);
  }
  if (command == 'V') {
    intensity = constrain(value, 0, 100);
  }
  if (command == 'L') {
    if (value == 0) {
      lcdActive = false;
      digitalWrite(lcdShutter, LOW);
    } else if (value == 250) {
      lcdActive = false;
      digitalWrite(lcdShutter, HIGH);
    } else {
      lcdActive = true;
      lcdDelay = map(value, 1, 249, 0, 16000);
      nextShutter = millis() + lcdDelay;
    }
  }
  if (command == 'I') {
    fadeIn = map(value, 0, 250, 0, 4000);
    SoftPWMSetFadeTime(ALL, fadeIn, fadeOut);
  }
  if (command == 'O') {
    fadeOut = map(value, 0, 250, 0, 4000);
    SoftPWMSetFadeTime(ALL, fadeIn, fadeOut);
  }
  if (command == 'R') {
    randomSeed(value);
    id = value;
    value++;
    value = value % 250;
    sendData(byte('R'), value);
  }
  if (command == 'F') {
    delay(random(value * 100));
  }
  if (command == 'f') {
    delay(value * id);
  }
  if (command == 'C') {
    probability = constrain(value, 0, 100);
  }
  if (command == 'B') {
    createBurst(value);
  }
  if (command == 'b') {
    createRelativeBurst(value);
  }
  if (command == 'A') {
    if (value == 0) {
      autoBursting = false;
    } else {
      autoBursting = true;
      autoBurstFrequency = map(value, 1, 250, 1000, 60000);
    }
  }
}

void createBurst() {
  burstEnd = millis() + burstDuration;
  if (!bursting) {
    oldProbability = probability;
    probability = 100;
    bursting = true;
  }
}

void createBurst(byte dur) {
  burstDuration = map(dur, 0, 250, 0, 10000);
  burstEnd = millis() + burstDuration;
  if (!bursting) {
    oldProbability = probability;
    probability = 100;
    bursting = true;
  }
}

void createRelativeBurst(byte dur) {
  burstDuration = map(dur, 0, 250, 0, 10000);
  burstEnd = millis() + burstDuration;
  if (!bursting) {
    oldProbability = probability;
    probability = constrain(probability * 5, 0, 100);
    bursting = true;
  }
}

void sendData(byte command, byte value) {
  digitalWrite(txLed, HIGH);
  Serial.write(255);
  Serial.write(command);
  Serial.write(value);
  digitalWrite(txLed, LOW);
}

void sendDoubleData(byte command, byte value1, byte value2) {
  digitalWrite(txLed, HIGH);
  Serial.write(254);
  Serial.write(command);
  Serial.write(value1);
  Serial.write(value2);
  digitalWrite(txLed, LOW);
}

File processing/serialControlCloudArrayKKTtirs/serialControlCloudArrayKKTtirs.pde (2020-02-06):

import processing.serial.*;
import controlP5.*;

ControlP5 cp5;
String arduinoMega = "/dev/ttyACM4";
Serial arduino;

int delayBeforeStart, delayMultiplier, loopCount, program, stepDelay = 15;
int lcdDelay, intensity = 100;
boolean channel1 = true, channel2 = true, channel3 = true;

void setup() {
  size(600, 600);

  printArray(Serial.list());
  arduino = new Serial(this, arduinoMega, 115200);

  // robot controls
  cp5 = new ControlP5(this);
  cp5.addSlider("program").setRange(0, 6).setPosition(10, 30).setWidth(360).addCallback(  
    new CallbackListener() {
    public void controlEvent(CallbackEvent theEvent) {
      switch(theEvent.getAction()) {
        case(ControlP5.ACTION_RELEASED):
        case(ControlP5.ACTION_RELEASEDOUTSIDE):
        sendData('P',byte(program));
        break;
      }
    }
  }
  );
  cp5.addSlider("stepDelay").setRange(0, 250).setPosition(10, 40).setWidth(360).addCallback(  
    new CallbackListener() {
    public void controlEvent(CallbackEvent theEvent) {
      switch(theEvent.getAction()) {
        case(ControlP5.ACTION_RELEASED):
        case(ControlP5.ACTION_RELEASEDOUTSIDE):
        sendData('S',byte(stepDelay));
        break;
      }
    }
  }
  );
  cp5.addSlider("lcdDelay").setRange(0, 250).setPosition(10, 50).setWidth(360).addCallback(  
    new CallbackListener() {
    public void controlEvent(CallbackEvent theEvent) {
      switch(theEvent.getAction()) {
        case(ControlP5.ACTION_RELEASED):
        case(ControlP5.ACTION_RELEASEDOUTSIDE):
        sendData('L',byte(lcdDelay));
        break;
      }
    }
  }
  );
  cp5.addSlider("intensity").setRange(0, 250).setPosition(10, 60).setWidth(360).addCallback(  
    new CallbackListener() {
    public void controlEvent(CallbackEvent theEvent) {
      switch(theEvent.getAction()) {
        case(ControlP5.ACTION_RELEASED):
        case(ControlP5.ACTION_RELEASEDOUTSIDE):
        sendData('V',byte(intensity));
        break;
      }
    }
  }
  );
  cp5.addButton("send").setSize(70, 18).setPosition(10, height-60);
  cp5.addButton("pulse").setSize(70, 18).setPosition(10, height-40);
  cp5.addToggle("channel1").setSize(70,18).setPosition(10,height-100);
  cp5.addToggle("channel2").setSize(70,18).setPosition(85,height-100);
  cp5.addToggle("channel3").setSize(70,18).setPosition(160,height-100);
  
  // stylish
  cp5.setColorActive(color(225));
  colorMode(HSB, 255);
  cp5.setColorBackground(color(random(255), 100, 100));
  cp5.setColorForeground(color(random(255), 100, 150));
  colorMode(RGB);
}

void draw() {
  background(0);
}

void send() {
  println("send!");
}

void pulse() {
  arduino.write("GO");
}

void serialEvent(Serial arduino) {
  char incomingChar = arduino.readChar();
  print (incomingChar);
}

void sendData(char command, int val) {
  arduino.write(unsignedByte(255));
  arduino.write(command);
  arduino.write(unsignedByte(val));
}

void channel1(boolean theFlag) {
  sendData('C',int(theFlag));
}
void channel2(boolean theFlag) {
  sendData('C',2+int(theFlag));
}
void channel3(boolean theFlag) {
  sendData('C',4+int(theFlag));
}

byte unsignedByte( int val ) { return (byte)( val > 127 ? val - 256 : val ); }

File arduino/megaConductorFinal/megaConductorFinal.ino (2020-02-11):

int led [] = {50, 46, 42};
boolean active [] = {true, true, true};
int tickLed = 13;
unsigned long nextTick = millis();
int seconds = 0;
boolean tock = false, ticked = false;
int nextProgramChange = 1;
int morphingParameter = -1, startVal = -1, endVal = -1, morphLength = -1, morphProgression = -1, morphVal = -1, lastMorphVal = -1, peakDuration = -1;
boolean morphing = false, morphRiseAndFall = true, morphLooping = true;
int morphState = -1;
byte formation = 0b00000111;

unsigned int lastMorph;
int morphFreq = 40, lastFeedbackSec = -1;
int counterActionFrequency = 10, counterAction = -1, counterLow = 0, counterHigh = 251;
int burstChance = -1;

int currentPreset = -1;

#define RISE 0
#define PEAK 1
#define FALL 2
#define DONE 3

int program = 2, lastProgram = -1, amountOfPrograms = 14;
#define REST 0
#define STARS 1
#define KNIGHTRIDER 2
#define SOLID 3
#define BLINKSOLID 4
#define VU 5
#define MIDDLEVU 6
#define DIRECTIONAL 7
#define RANDOMBITS 8

#define NONE 0
#define STEPDELAY 1
#define INTENSITY 2
#define PROBABILITY 3
#define LCDFREQUENCY 4

int slowness = 15;
boolean morphFeedback = false;

void setup() {
  Serial.begin(115200);
  Serial1.begin(115200);
  Serial2.begin(115200);
  Serial3.begin(115200);
  for (int i = 0; i < 3; i++) {
    pinMode(led[i], OUTPUT);
    digitalWrite(led[i], active[i]);
  }
  pinMode(tickLed, OUTPUT);

  // random seed and id
  sendData('R', 0);
  nextProgramChange = 10;
  preset(13);

}

void loop() {
  tick();
  if (ticked) {
    Serial.print(seconds);
    Serial.print(".");
    if (seconds >= nextProgramChange * slowness) {
      int nextPreset = currentPreset;
      while (currentPreset == nextPreset) {
        nextPreset = random(10);
      }
      preset(nextPreset);
    }
    if (seconds % counterActionFrequency == 0) {
      doCounterAction();
    }
  }
  if (morphing && lastMorph + morphFreq < millis()) {
    morphProgression++;
    morph();
    lastMorph = millis();
  }
  if (burstChance > 0) {
    int ran = random(10000);
    if (ran < burstChance) {
      sendData('B', random(30));
    }
  }
  delay(20);
}

void doCounterAction() {
  Serial.println("counterAction time");
  formation = ~formation;
  if (counterAction == LCDFREQUENCY) {
    sendData('L', random(counterLow, counterHigh));
  }
  if (counterAction == INTENSITY) {
    sendData('V', random(counterLow, counterHigh));
  }
  formation = ~formation;
}

void rest() {
  Serial.print("resting");
  delay(random(500, 5000));
  Serial.println(".");
}

void preset(int _preset) {
  currentPreset = _preset;
  rest();
  morphing = false;
  Serial.print("change preset to ");
  Serial.println(currentPreset);

  int ran = random(3);
  switch (currentPreset) {
    case 0:
      Serial.println("directionals");
      formation = 0b00000111;
      sendData('I', 10);
      sendData('O', random(50, 250));
      sendData('S', random(150, 250));
      sendData('C', random(1, 5));
      programChange(DIRECTIONAL);
      newMorph(PROBABILITY, random(100), 0, random(200, 800), true, true);
      formation = 0b00000101;
      nextProgramChange = random(5, 7);
      counterActionFrequency = random(13, 25);
      counterAction = STEPDELAY;
      counterHigh = 251;
      counterLow = 20;
      break;
    case 1:
      Serial.println("stars");
      formation = 0b00000111;
      sendData('L', random(100, 150));
      programChange(STARS);
      sendData('I', random(5));
      sendData('O', random(200, 251));
      sendData('S', random(5, 25));
      formation = 0b00000101;
      newMorph(STEPDELAY, random(30, 100), random(0, 15), random(200, 800), true, true);
      counterAction = STEPDELAY;
      counterHigh = 35;
      counterLow = 1;
      burstChance = random(100);
      nextProgramChange = random(4);
      break;
    case 2:
      Serial.println("totes random");
      if (ran == 0) formation = 0b00000111;
      if (ran == 1) formation = 0b00000101;
      if (ran == 2) formation = 0b00000010;
      programChange(random(0, amountOfPrograms));
      newMorph(random(4), random(0, 50), random(200, 250), random(200, 800), true, true);
      counterAction = random(1, 5);
      counterHigh = random(255);
      counterLow = 0;
      burstChance = random(100);
      nextProgramChange = random(4);
      break;
    case 3:
      Serial.println("hectic stuff");
      formation = 0b00000111;
      sendData('I', 0);
      sendData('O', random(1, 25));
      sendData('S', random(0, 10));
      nextProgramChange = random(2);
      break;
    case 4:
      Serial.println("rest");
      programChange(REST);
      nextProgramChange = random(1, 2);
      break;
    case 5:
      Serial.println("chill trails");
      formation = 0b00000111;
      sendData('I', random(5));
      sendData('O', random(10, 250));
      nextProgramChange = 0;
      break;
    case 6:
      Serial.println("LCD frequency");
      formation = 0b00000111;
      newMorph(LCDFREQUENCY, random(0, 251), random(30, 251), random(50, 200), false, false);
      nextProgramChange = 2;
      break;
    case 7:
      Serial.println("VU middle");
      formation = 0b00000010;
      sendData('I', 0);
      sendData('O', random(1, 25));
      sendData('S', random(0, 10));
      programChange(MIDDLEVU);
      newMorph(STEPDELAY, random(0, 30), random(30, 251), random(50, 200), true, true);
      nextProgramChange = random(1, 3);
      break;
    case 8:
      Serial.println("autoburst on");
      if (ran == 0) formation = 0b00000111;
      if (ran == 1) formation = 0b00000101;
      if (ran == 2) formation = 0b00000010;
      sendData('A', random(1, 251));
      break;
    case 9:
      Serial.println("autoburst off");
      formation = 0b00000111;
      sendData('A', 0);
      break;
    case 10:
      Serial.println("new counter action frequency");
      counterActionFrequency = random(0, 200);
      break;
    case 11:
      Serial.println("knight rider relative");
      programChange(KNIGHTRIDER);
      sendData('I', 0);
      sendData('O', 20);
      sendData('S', 0);
      sendData('s', 1);
      break;
    case 12:
      Serial.println("fast LCD shutter");
      sendData('L', random(0, 15));
      break;
    case 13:
      Serial.println("random bits");
      sendData('I', 1);
      sendData('O', random(50));
      sendData('P', 8);
      sendData('S', random(15));
      break;
    default:
      break;

  }
  Serial.print("new preset ");
  Serial.print(_preset);
  Serial.print(": ");
  printMorphSettings();
  currentPreset = _preset;
}
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

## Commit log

2020-02-06 eagle files are too messy
    [cloudArray2.brd, cloudArray2.sch]
2020-02-11 final arduino, added pics, readme updated

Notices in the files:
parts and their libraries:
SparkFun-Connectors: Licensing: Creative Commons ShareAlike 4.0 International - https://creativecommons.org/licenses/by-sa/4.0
